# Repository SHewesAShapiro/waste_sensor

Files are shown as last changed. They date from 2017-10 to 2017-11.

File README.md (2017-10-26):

# waste_sensor
senses the level in a waste flask and creates an alert

Abstract:
Waste flasks fill up fast in labs that do a lot of cell culture. Keeping track of waste is a tedious task that causes conflict if lab members forget or neglect this chore. The waste flask can also overflow if seriously neglected, causing damage to the system. We propose to create a simple light-based sensor and alert system. This will sense whether the waste level is above a certain level, indicating that it is time for the container to be emptied. It will then email the lab member who is next in line to empty it. It will send several reminders and then threaten to email the member's boss if the alert goes unanswered.

Brainstorm:
getting people to empty waste flasks is a pain and causes lab drama
With an automated system you decrease the need to have awkward conversations with your labmates and strain relationships
You can't claim it's not your turn because the system knows who's next! You can't claim you forgot because the system keeps track

a simple light sensor will give an alert when a flask is full
It will sense a difference in air in your flask compared to clear liquid (or any non-air thing inside the beaker) - could be non-clear liquid
It will do a check every minute to see the status of the flask

It will then send you several email reminders until you do it
If you don't, it will threaten to -- and ultimately will -- email your boss!

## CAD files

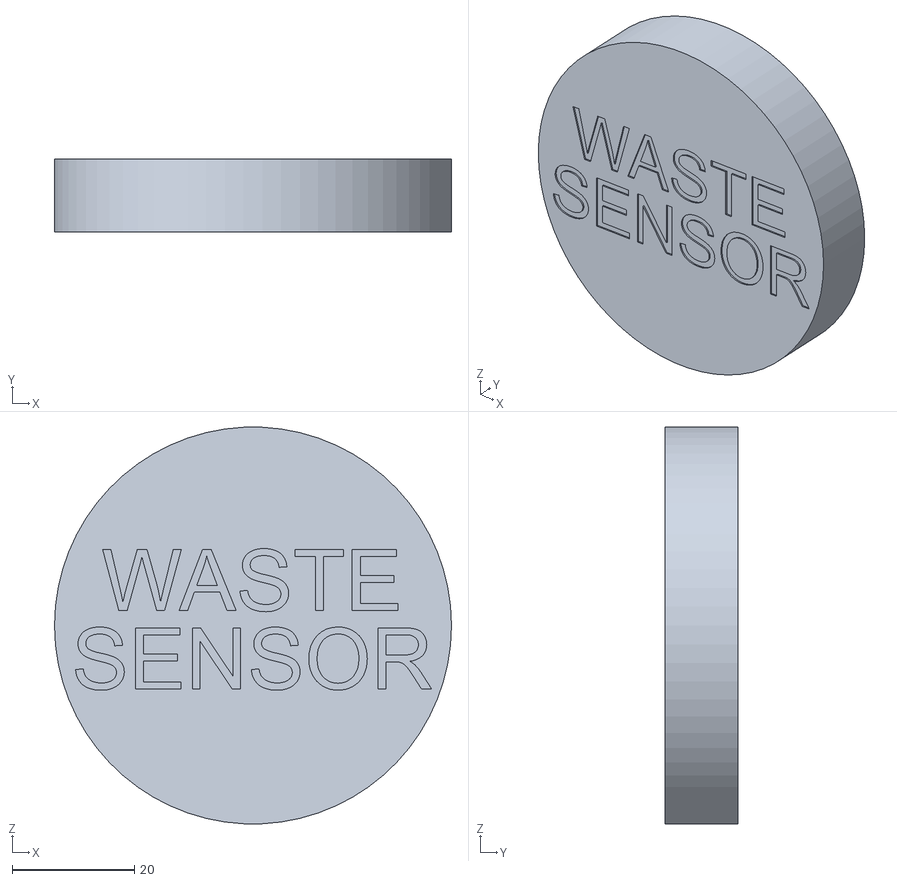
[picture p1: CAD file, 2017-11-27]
sensor cap 2.stl
65.0 x 12.0 x 64.9

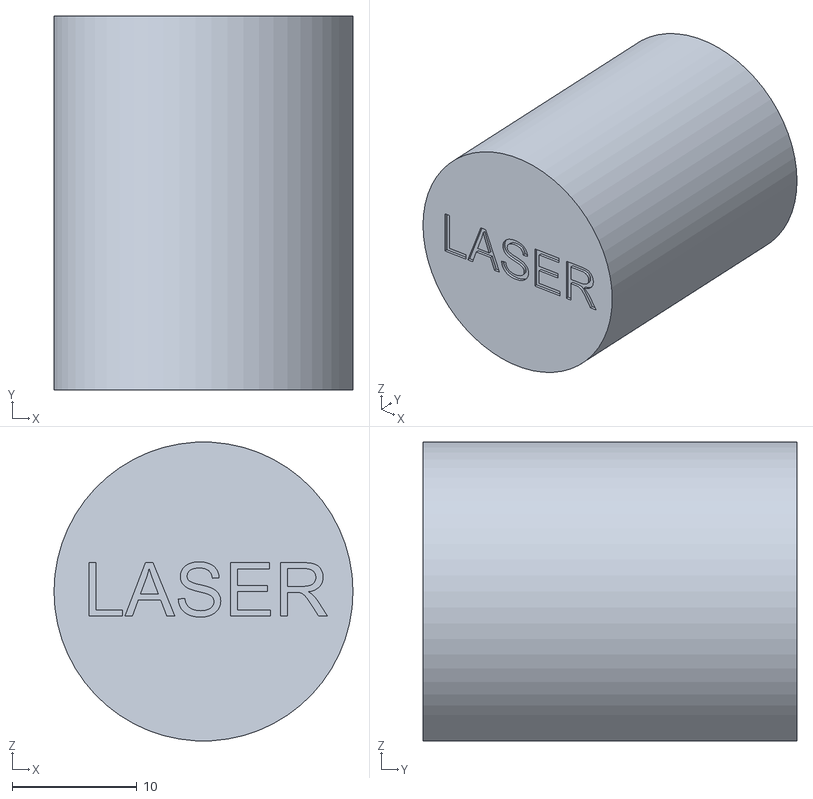
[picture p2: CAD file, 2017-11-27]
laser cap 2.stl
24.0 x 30.0 x 24.0

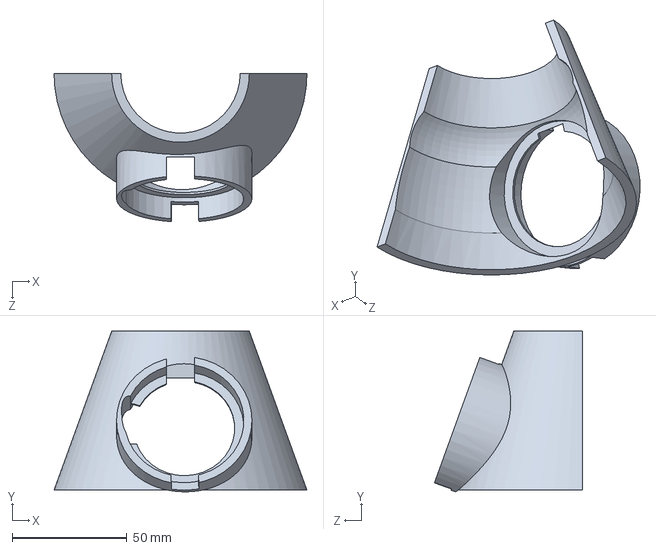
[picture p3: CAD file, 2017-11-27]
Clasp with circuit playground holder 112617 v7.SLDPRT
110.3 x 70.0 x 64.6 mm

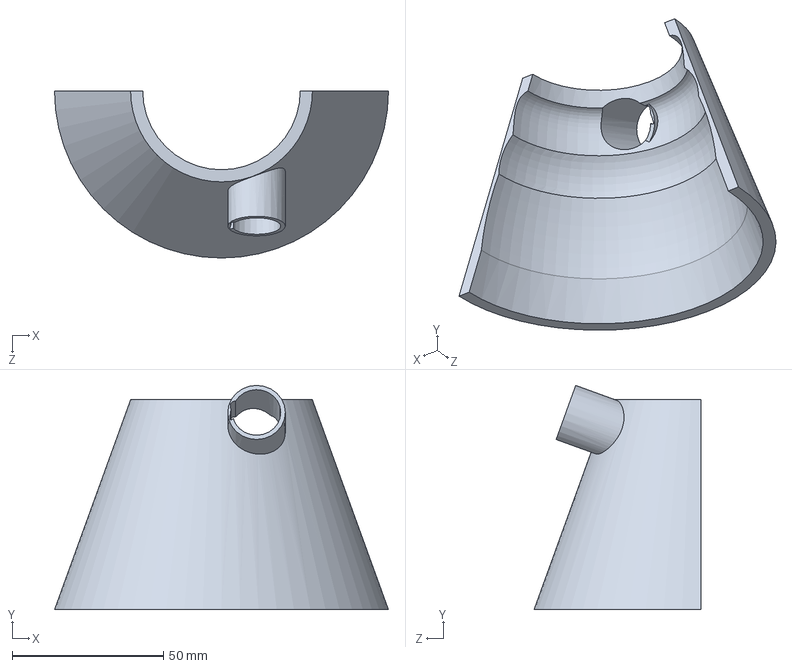
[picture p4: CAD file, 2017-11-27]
Clasp with laser pointer holder 112617 v7.SLDPRT
110.3 x 74.0 x 55.1 mm

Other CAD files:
Clasp with circuit playground holder 112617 v7.STL
Clasp with laser pointer holder 112617 v7.STL

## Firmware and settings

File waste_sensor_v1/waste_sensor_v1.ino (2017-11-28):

/* Waste sensor
 *  Monitors the liquid level in a tissue culture waste flask and responds
 *  to the flask being filled past a threshold and emptied. 
 *  
 *  Laser attaches to GND (black) and pin #9 (red)
 *  
 *  by Alyssa Shapiro and Sarah Hewes
 */
 
#include <Adafruit_CircuitPlayground.h>

// initialize values
int value;
int escalation = 0;
boolean flaskfull = false;
float X;
int count;
int timecount;

void setup() {
  //start the serial output
  Serial.begin(9600);
  //start the circuit plaground
  CircuitPlayground.begin();
  //change the mode of pin #9 to output
  pinMode(9, OUTPUT);
}

void loop() {
  
  //turn laser on and check light level
  digitalWrite(9, HIGH);
  value = CircuitPlayground.lightSensor();
  digitalWrite(9,LOW);

  //print out value for debugging
  Serial.print("Light Sensor: ");
  Serial.println(value);

  //double check 
  //if the light intensity is below a threshold, the laser has been deflected, then sound the alarm
  if (value < 400) {
    //wait 15 min and test again00
    delay(90000); //15 min power saving mode
    
      //turn laser on and check light level
      digitalWrite(9, HIGH);
      value = CircuitPlayground.lightSensor();
      delay(500);
      digitalWrite(9,LOW);
    
    if (value < 400) {    
            //beep an alert for one minute
            for (int i=0; i <= 60; i++) {
            CircuitPlayground.playTone(500, 100);            
            delay(50);
            }
            
            //enter while loop
            flaskfull = true;
            while (flaskfull) {
              //turn off laser
                digitalWrite(9,HIGH);
                      
              //increments escalation level
                escalation++;

                //for 24 hours flash constantly and check for accelerometer inversion
                while (escalation > 0) {

                    //once time has passed increment the escalation level at 24 and 48 hours
                    if (timecount == 86400) {
                      escalation++;
                    }
                    if (timecount == 172800) {
                      escalation++;
                    }

                    //turns on red LEDs
                    for (int x=0; x <= 9; x++) {
                       CircuitPlayground.setPixelColor(x, 255,   0,   0);
                    }
                    
                    //print escalation level to serial
                    if (escalation == 1) {
                      //emails you nicely
                      Serial.println("kitten");
                    }
                    else if (escalation == 2) {
                      //emails you grumpily
                      Serial.println("cat");
                    }
                    else if (escalation >=3) {
                      //emails your PI
                      Serial.println("tiger");
                    }
                   
                    //listens for accelerometer change
                      X = CircuitPlayground.motionX();
                    //if accelerometer detects inversion, then reset everything
                           Serial.println(X);
                    //if the flask has been inverted
                    if (X > 1) {
                      Serial.println("5 second check");
                      count = 0;
                      for (int j=0; j<=10; j++){
                        X = CircuitPlayground.motionX();
                        if (X > 1){
                          count++;
                          CircuitPlayground.setPixelColor(j, 0,   255,   0);
                          }
                        delay(500);                        
                      }
                     //if the flask has been inverted for 5 seconds then the flask has been emptied
                      if (count >= 10){
                        escalation = 0;
                        flaskfull = false;
                        timecount = 0;
                        //blue light
                         for (int x=0; x <= 9; x++) {
                       CircuitPlayground.setPixelColor(x, 0,   0,   255);
                        }     
                       //while x is positive (flask not inverted) keep listening
                       while (X > 1){
                        delay(1000);
                        X = CircuitPlayground.motionX();
                       }
                       //turns off LEDs as the sensor is reset
                      CircuitPlayground.clearPixels();            
                      }
                    }
                                        
                    delay(500); 
                    //turns off LEDs (for flashing)
                    CircuitPlayground.clearPixels();
                    delay(1000); 
                    //keeps track of the amount of time the device has been in an alarm state
                    timecount++;
                }
            }                   
    }
  }
  delay(90000); //15 min pause
}

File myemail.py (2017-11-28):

#Cell culture waste sensor (additional email functionality)
#Alyssa Shapiro and Sarah Hewes 2017
#When run approximately every 15 minutes on a chrontab, this code will allow the raspberry pi to obtain serial information from
#the circuit playground and send emails to the student and PI involved with cell culture maintance

import serial
import time
import smtplib

#open the serial port
ser = serial.Serial('/dev/ttyACM0', 9600)

#pause while the serial feed fills
time.sleep(10)

#read a line from the serial feed
read_serial = ser.readline()

#initialize email information
smtpUser = 'alyssamshapiro@gmail.com'
smtpPass = '********' #password redacted
gradstudent = 'sh62@rice.edu'
fromAdd = smtpUser

s = smtplib.SMTP('smtp.gmail.com',587)
s.ehlo()
s.starttls()
s.ehlo()

s.login(smtpUser,smtpPass)

#if the serial feed shows various keywords then send emails of increasing urgency
#first two emails go to the student. the last one goes to the PI
if read_serial.find("kitten") > -1: 
	subject = 'Its your turn to change the waste container!'
	header = 'To: ' + gradstudent + '\n' + 'From: ' + fromAdd + '\n' + 'Subject: ' + subject
	body = 'Please empty the waste container! This is your FIRST warning.'  
	print header + '\n\n' + body
	s.sendmail(fromAdd, gradstudent, header + '\n\n' + body)
elif read_serial.find("cat") > -1:
	subject = 'Its your turn to change the waste container! SECOND WARNING!'
	header = 'To: ' + gradstudent + '\n' + 'From: ' + fromAdd + '\n' + 'Subject: ' + subject
	body = 'Please empty the waste container! This is your SECOND warning, Next, I will email your PI!' 
	print header + '\n\n' + body
	s.sendmail(fromAdd, gradstudent, header + '\n\n' + body) 
elif read_serial.find("tiger") > -1:
	subject = 'Your grad student has not emptied the waste flask!'
	header = 'To: ' + smtpUser + '\n' + 'From: ' + fromAdd + '\n' + 'Subject: ' + subject
	body = 'Sarah Hewes has neglected to empty the waste flask!' 
	print header + '\n\n' + body
	s.sendmail(fromAdd, smtpUser, header + '\n\n' + body) 
else:
	print "normal operation"

s.quit()

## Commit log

2017-10-26 Branstorm of the waste sensor project
2017-11-06 circuit playground waste sensor program
    circuit playground will beep every 10 seconds if the waste level in the flask deflects the laser
2017-11-14 added responsiveness, timed checking, and escalation framework
2017-11-15 added laser function and additional pouring animation
2017-11-27 optional raspberry pi functionality
2017-11-27 perfected email function, finished arduino code waste_sensor_v1
2017-11-27 old version of 3D model
    [Clasp with circuit playground hole 110617.SLDPRT]
2017-11-27 Final versions of 3d printed plastic casing
    [Clasp with circuit playground holder 112617 v7.SLDPRT, Clasp with circuit playground holder 112617 v7.STL, Clasp with laser pointer holder 112617 v7.SLDPRT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]
